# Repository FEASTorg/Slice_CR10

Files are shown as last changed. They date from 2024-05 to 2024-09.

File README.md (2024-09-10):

# 10A Current Reader Slice

10A Current Reader Slice for BREAD.

## Introduction

[Short introduction on the project.]

## Usage

[Explain how to use the project. Include examples and screenshots if applicable.]

## Documentation

Please refer to the [docs](/docs) for more info.

---

<div align="center">
  <p>
    
    
  </p>
</div>

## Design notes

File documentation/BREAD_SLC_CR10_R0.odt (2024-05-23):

# Broadly Reconfigurable and Expandable Automation Device (BREAD) – Slice Datasheet: 10A Current Sensor Slice (SLC-CR10)

By: Nicholas Whisman (ngwhisma@mtu.edu) – Revision 0, on 17. May 2021

## Short Device Description

This slice acts as a current sensor, and is rated for up to ±10 Amps. The sensor outputs a voltage signal linearly related to the current flowing through the chip, at an approximate resolution of 200 mV / Amp.

## Quick Information

Device at a Glance

Short title | 10A Current Detector
Part # | SLC-CR10
Repository Link | Link to OSF or other repository
Academic Paper DOI | DOI link to published paper
Device Cost | Monetary cost of the device
Assembly Difficulty | Medium. Millable.
Application Area | Power Analysis, Controls

Device Connections

Current Input Screw Terminals

Pin # | Description | Rating
J2 | Screw terminal connection points for desired current to measure. Positive lead connects to right side of terminal. | 10A
J3 | Screw terminal connection points for desired current to measure. Positive lead connects to right side of terminal. | 10A
J4 | Screw terminal connection points for desired current to measure. Positive lead connects to right side of terminal. | 10A
J5 | Screw terminal connection points for desired current to measure. Positive lead connects to right side of terminal. | 10A

## Commands

Setup (no significant returns)
Byte: Address | Bit: 1 | Float: Target Temp | Float: Ramp Rate (d/m)
Read Current (returns the current through the selected channel)
Byte: Address | Bit: 0 | Float: 0 | Float: 0

## Schematic

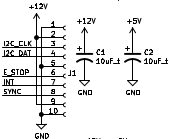
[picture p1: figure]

Figure 1: BREAD Connection Pins + Power Capacitors

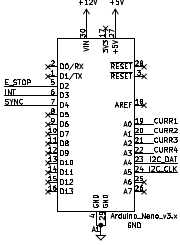
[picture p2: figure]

Figure 2: Arduino Nano

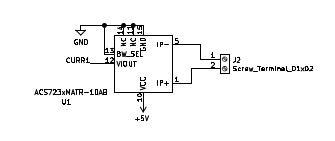
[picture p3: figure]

Figure 3: One of four identical current sensing channels

## Bill of Materials

Designator | Description | Quantity | Cost / part | URL
U1-4 | 10A Current Sensor Chip | 4 | 5.68 | https://www.digikey.com/en/products/detail/allegro-microsystems/ACS723KMATR-10AB-T/5225374
J2-J5 | 1/10” Pitch 01x02 Screw Terminals | 4 | 1.27 | https://www.digikey.com/en/products/detail/te-connectivity-amp-connectors/282834-2/1150135
C1-2 | 1206 Packaging 10 µF Capacitor | 2 | 0.64 | https://www.digikey.com/short/qfrbqfhd
A1 | Arduino Nano | 1 | 22.00 | https://www.digikey.com/en/products/detail/arduino/A000005/2638989
J1 | 01x10 Female Header Pins | 1 | 0.79 | https://www.digikey.com/short/23bfwwjh

## Construction & Fabrication

List any tools that are required and short guide on the order which parts should be soldered / assembled. Be sure to note any specialized methods and point out components that may easily be soldered in the incorrect orientation. Additionally include at least one picture of the assembled board (include both sides if there are components on both sides).

[Image of the assembled Circuit Board]

Fig #. Subtitle should go here.

## Configuration & Calibration

Include a list of default jumper and potentiometer positions:

Hardware Positions

- Turn P1 to be roughly 50%
- Turn P2 to be completely closed (turn clockwise until potentiometer clicks)
- Place a jumper to short out J3. Etc…

Detail any key parameters the end-user may want to adjust in the firmware, and if there are any special instructions before programming the Slice.

Tools Required For Calibration

- An oscilloscope with at least 15Mhz sampling
- A multimeter. Etc…

List all of the tools / instruments required for calibration. Provide a detailed & step by step guide on how to calibrate (or validate) each unique type of channel on the card. Include what variables in the firmware may need to be adjusted (and when). Attach a wiring diagram for each relevant calibration circuit.

[Image of the calibration circuit]

Fig #. Subtitle should go here.

## Usage & Constraints

List the relevant constraints for each type of channel on the card. These parameters may be quantities like max current, max voltage, frequency, sampling frequency, etc.

List an example wiring diagram of the slice in use, as well as some suggested applications

[Image of the example usage wiring diagram]

Fig #. Subtitle should go here.

## General Comments on Slice

This section is intended as a catch-all for any topics that are relevant to the Slice that don’t fit in any other category.

## Revision Notes

- Rev 0 – Initial document release (DATE HERE)

SLC-CR10 Datasheet – Revision 0

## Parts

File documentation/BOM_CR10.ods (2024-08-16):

Id | Designator | Package | Quantity | Designation | Supplier and ref
1 | U4,U3,U2,U1 | SOIC-16W_7.5x10.3mm_P1.27mm | 4 | ACS723KMATR-10AB-T | https://www.mouser.ca/ProductDetail/Allegro-MicroSystems/ACS723KMATR-10AB-T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
2 | J5,J4,J3,J2 | Fixed Terminal Blocks TDPT 4/ 2-SP-6,35-ZB | 4 | Screw_Terminal_01x02 | https://www.mouser.ca/ProductDetail/Phoenix-Contact/1017521?qs=F5EMLAvA7IBBb3TEAcTBBg%3D%3D
3 | C1,C2 | C_2312 | 2 | 10uF_t | https://www.mouser.ca/ProductDetail/Kyocera-AVX/TAJC106K016PNJ?qs=ZjRtS80k2UMUMDO3iOPrkg%3D%3D
4 | A1 | Arduino_Nano | 1 | Arduino_Nano_v3.x | https://www.digikey.ca/en/products/detail/arduino/A000005/2638989
5 | J1 | PinSocket_1x10_P2.54mm_Horizontal | 1 | Conn_01x10_Female | https://www.digikey.ca/en/products/detail/sullins-connector-solutions/PPPC101LGBN-RC/775943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

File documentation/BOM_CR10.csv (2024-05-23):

Id | Designator | Package | Quantity | Designation | Supplier and ref
1 | U4,U3,U2,U1 | SOIC-16W_7.5x10.3mm_P1.27mm | 4 | ACS723xMATR-10AB
2 | J5,J4,J3,J2 | TerminalBlock_TE_282834-2_1x02_P2.54mm_Horizontal | 4 | Screw_Terminal_01x02
3 | Logo1 | OSHW-Symbol_6.7x6mm_SilkScreen | 1 | Logo_Open_Hardware_Small
4 | H4,H3,H2,H1 | MountingHole_3.2mm_M3_DIN965_Pad | 4 | MountingHole
5 | C1,C2 | C_2312 | 2 | 10uF_t
6 | A1 | Arduino_Nano | 1 | Arduino_Nano_v3.x
7 | J1 | PinSocket_1x10_P2.54mm_Horizontal | 1 | Conn_01x10_Female

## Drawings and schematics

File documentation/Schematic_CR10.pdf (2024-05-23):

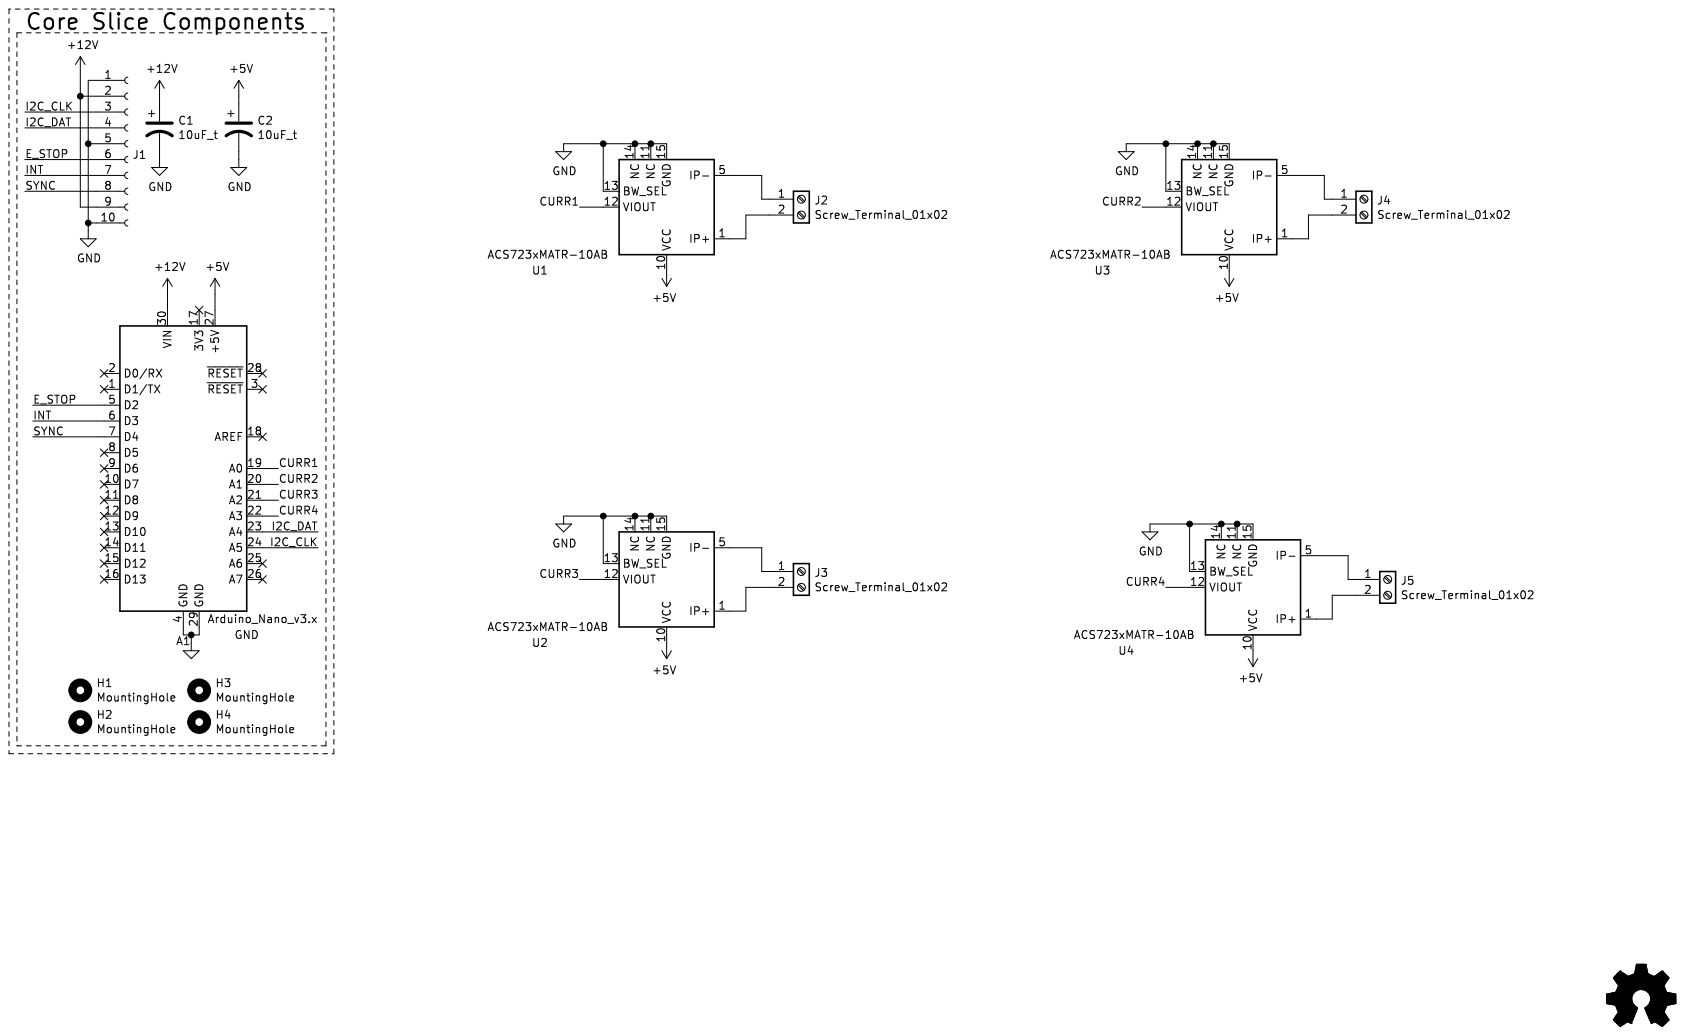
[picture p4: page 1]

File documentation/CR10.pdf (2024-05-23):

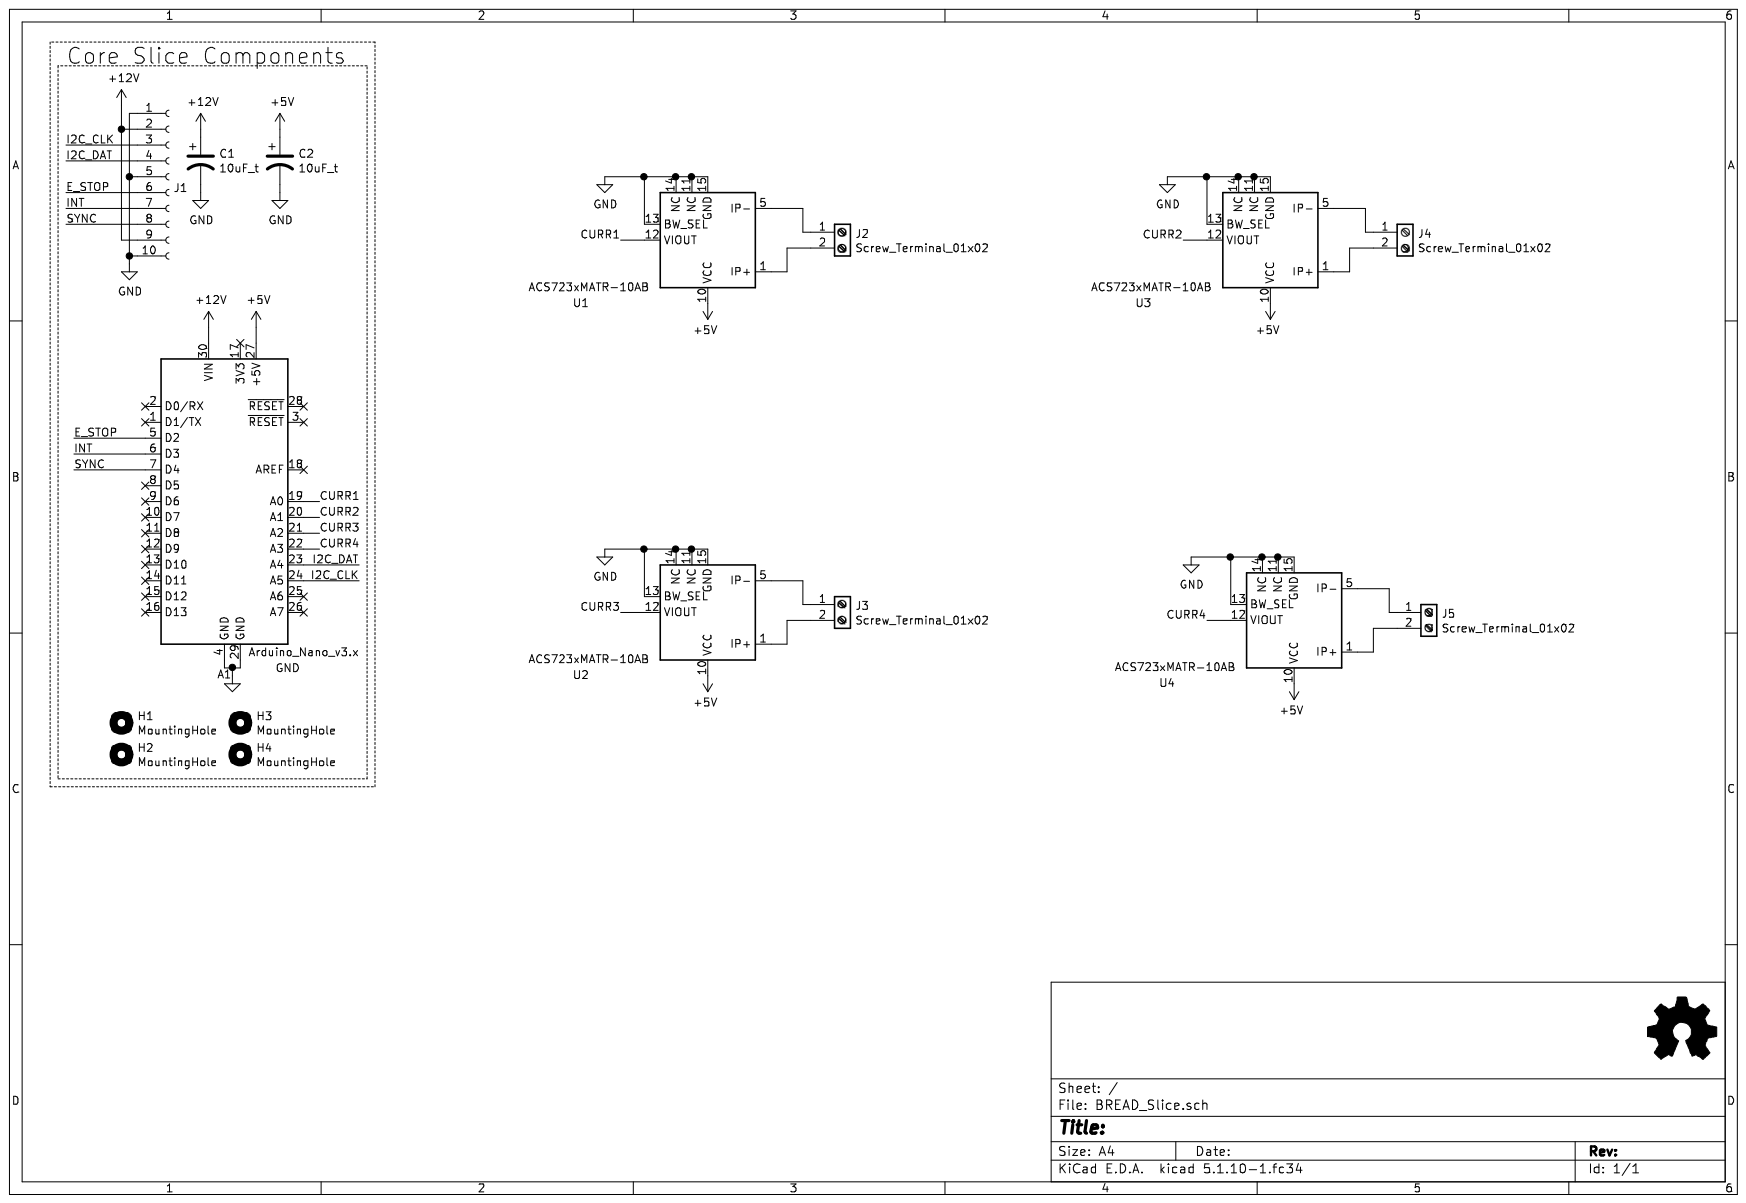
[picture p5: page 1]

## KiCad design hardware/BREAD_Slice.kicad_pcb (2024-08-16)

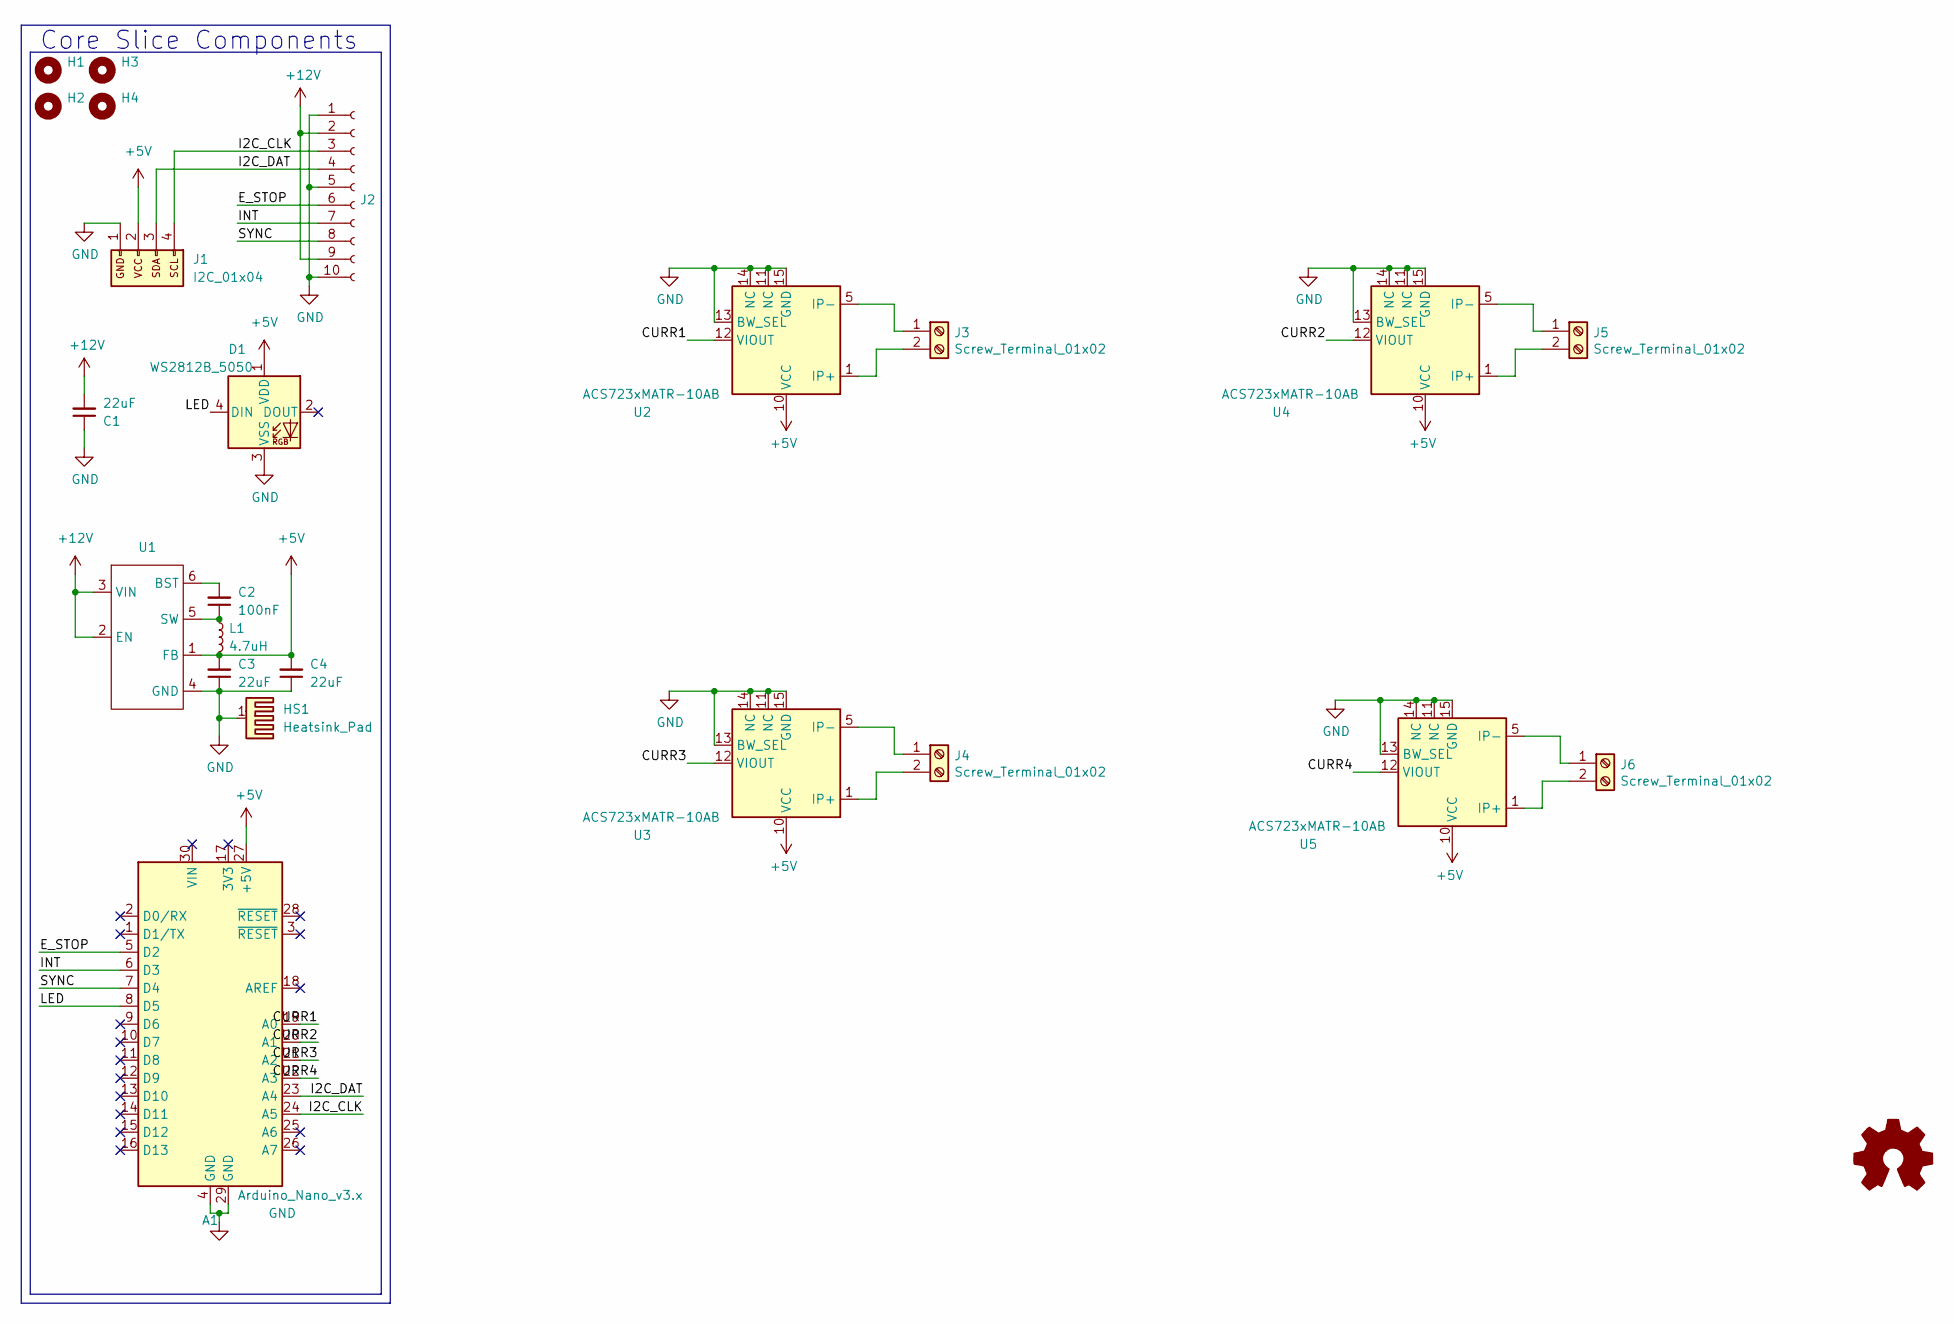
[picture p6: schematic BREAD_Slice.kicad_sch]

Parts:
A1: Arduino_Nano_v3.x; Arduino_Nano
C1, C3, C4: 22uF; C_1206_3216Metric
C2: 100nF; C_1206_3216Metric
D1: WS2812B_5050; WS2812-5050-4PIN
H1, H2, H3, H4: MountingHole; MountingHole_5mm
HS1: Heatsink_Pad; Thermal Pad
J1: I2C_01x04; JST_SH_SM04B-SRSS-TB_1x04-1MP_P1.00mm_Horizontal
J2: Conn_01x10_Female; PinSocket_1x10_P2.54mm_Horizontal
J3, J4, J5, J6: Screw_Terminal_01x02; Pheonix Conn Term TDPT 4 2-SP-6,35-ZB
L1: 4.7uH; L_1210_3225Metric
U1: TSOT-23-6
U2, U3, U4, U5: ACS723xMATR-10AB; SOIC-16W_7.5x10.3mm_P1.27mm

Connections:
+5V: A1.27 (+5V), C3.2, C4.2, D1.1 (VDD), J1.2, L1.2, U1.1 (FB), U2.10 (VCC), U3.10 (VCC), U4.10 (VCC), U5.10 (VCC)
+12V: C1.2, J2.2, J2.9, U1.2 (EN), U1.3 (VIN)
/CURR1: A1.19 (A0), U2.12 (VIOUT)
/CURR2: A1.20 (A1), U4.12 (VIOUT)
/CURR3: A1.21 (A2), U3.12 (VIOUT)
/CURR4: A1.22 (A3), U5.12 (VIOUT)
/E_STOP: A1.5 (D2), J2.6
/I2C_CLK: A1.24 (A5), J1.4, J2.3
/I2C_DAT: A1.23 (A4), J1.3, J2.4
/INT: A1.6 (D3), J2.7
/LED: A1.8 (D5), D1.4 (DIN)
/SYNC: A1.7 (D4), J2.8
GND: A1.4 (GND), A1.29 (GND), C1.1, C3.1, C4.1, D1.3 (VSS), HS1.1, J1.1, J2.1, J2.5, J2.10, U1.4 (GND), U2.11 (NC), U2.13 (BW_SEL), U2.14 (NC), U2.15 (GND), U3.11 (NC), U3.13 (BW_SEL), U3.14 (NC), U3.15 (GND), U4.11 (NC), U4.13 (BW_SEL), U4.14 (NC), U4.15 (GND), U5.11 (NC), U5.13 (BW_SEL), U5.14 (NC), U5.15 (GND)
unnamed: J3.1, U2.5 (IP-), U2.6 (IP-), U2.7 (IP-), U2.8 (IP-)
unnamed: J3.2, U2.1 (IP+), U2.2 (IP+), U2.3 (IP+), U2.4 (IP+)
unnamed: J4.1, U3.5 (IP-), U3.6 (IP-), U3.7 (IP-), U3.8 (IP-)
unnamed: J4.2, U3.1 (IP+), U3.2 (IP+), U3.3 (IP+), U3.4 (IP+)
unnamed: J5.1, U4.5 (IP-), U4.6 (IP-), U4.7 (IP-), U4.8 (IP-)
unnamed: J5.2, U4.1 (IP+), U4.2 (IP+), U4.3 (IP+), U4.4 (IP+)
unnamed: J6.1, U5.5 (IP-), U5.6 (IP-), U5.7 (IP-), U5.8 (IP-)
unnamed: J6.2, U5.1 (IP+), U5.2 (IP+), U5.3 (IP+), U5.4 (IP+)
unnamed: C2.2, U1.6 (BST)
unnamed: C2.1, L1.1, U1.5 (SW)

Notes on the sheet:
Core Slice Components

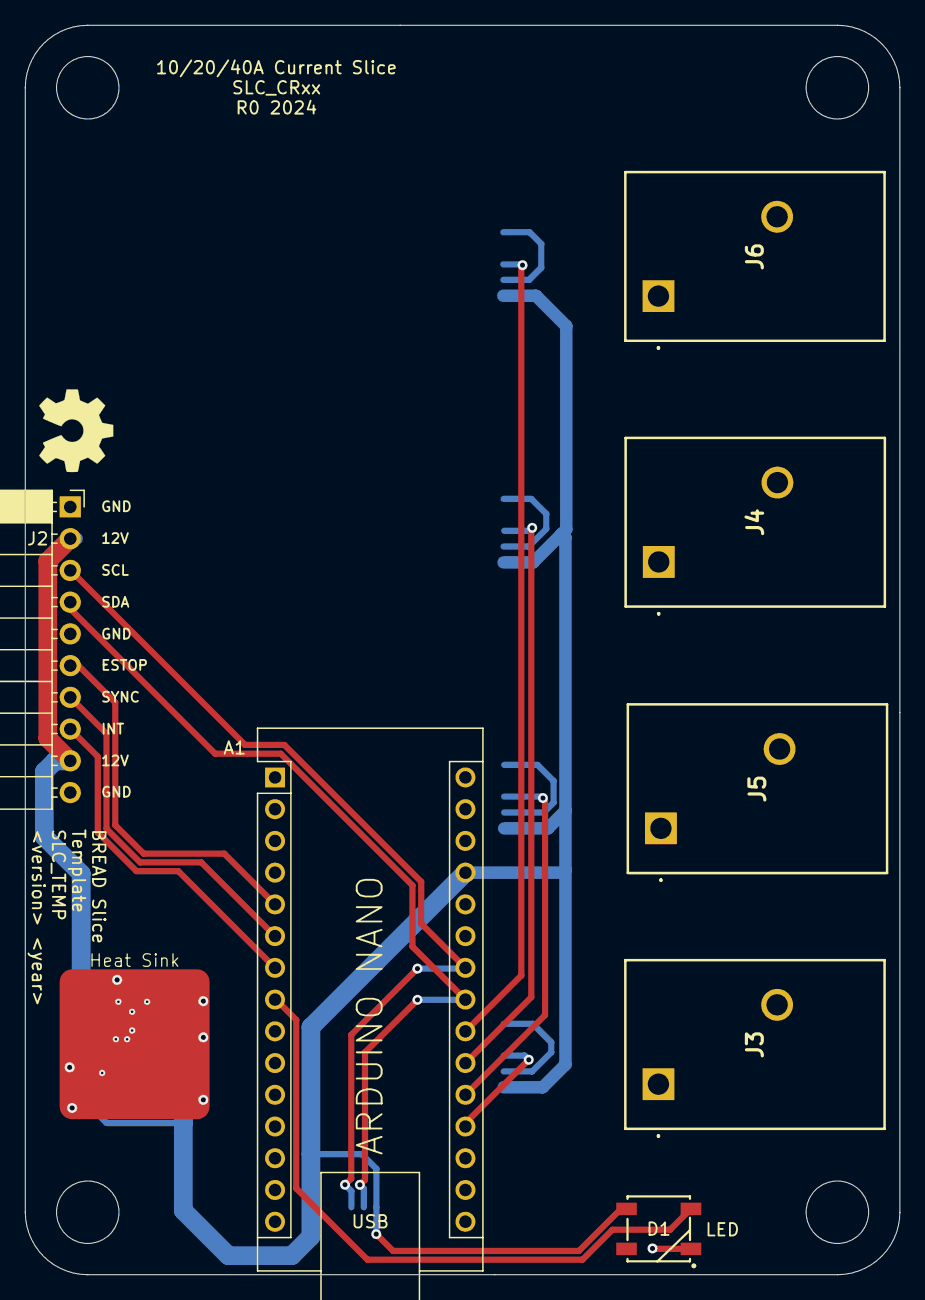
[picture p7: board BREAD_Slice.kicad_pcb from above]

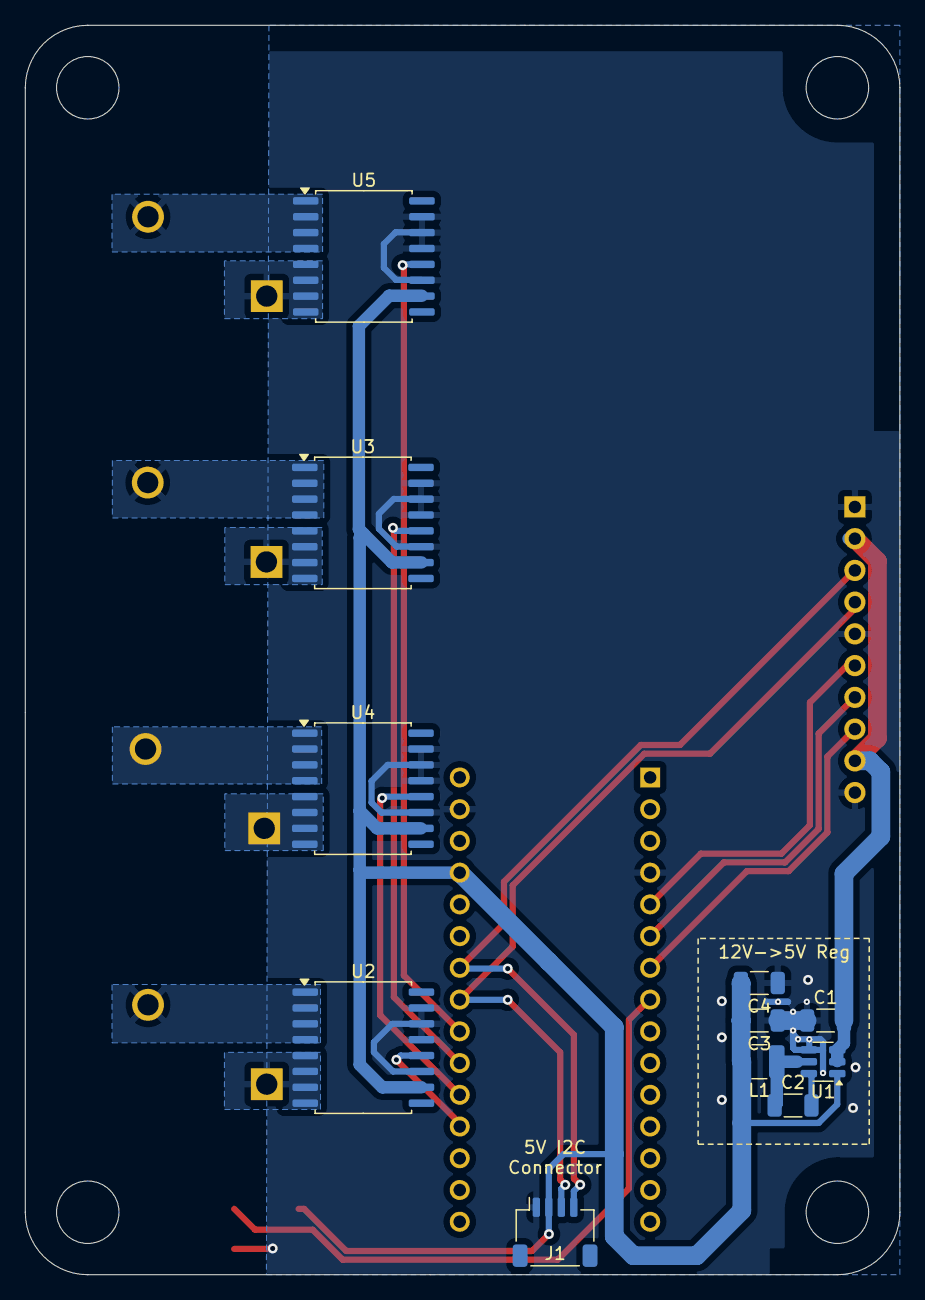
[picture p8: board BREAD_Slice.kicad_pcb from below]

Board: 2 copper layers, 70.0 x 100.0 mm, 24 parts (11 on the bottom side), 23 nets.

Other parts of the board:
Logo1: Logo_Open_Hardware_Small; OSHW-Symbol_6.7x6mm_SilkScreen

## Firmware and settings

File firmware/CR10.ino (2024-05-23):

#include <Wire.h>
#include <SPI.h>

#define I2C_ADR 18 //Set this however you want

typedef union //Define a float that can be broken up and sent via I2C
{
 float number;
 uint8_t bytes[4];
} FLOATUNION_t;

FLOATUNION_t RX_P1;
FLOATUNION_t RX_P2;
FLOATUNION_t RX_P3;
FLOATUNION_t RX_P4;


#define CURR1 A0
#define CURR2 A1
#define CURR3 A2
#define CURR4 A3

double CH1, CH2, CH3, CH4;

//Default all channels enabled
int CH1_T = 1;
int CH2_T = 1;
int CH3_T = 1;
int CH4_T = 1;

String inputString = "";         // a String to hold incoming data
boolean stringComplete = false;  // whether the string is complete

void setup() {
  // put your setup code here, to run once:
  Wire.begin(I2C_ADR);                // join i2c bus with address #8
  //Wire.onReceive(receiveEvent); // register event
  Wire.onRequest(requestEvent); // register event

  inputString.reserve(50);

  Serial.begin(115200);

  while (!Serial) delay(1); // wait for Serial on Leonardo/Zero, etc
  delay(500);

}

void loop() {

  //Add some way to read and save 'Zero' current for each channel?
  
  int filterStrength = 50;
  //Read in all current values, low-pass 'em
  for(int i=0; i<filterStrength; i++){
    CH1 += analogRead(CURR1);
    CH2 += analogRead(CURR2);
    CH3 += analogRead(CURR3);
    CH4 += analogRead(CURR4);
  }

  CH1 = ((CH1/filterStrength)*0.0244379275)-12.4;
  CH2 = ((CH2/filterStrength)*0.0244379275)-12.4;
  CH3 = ((CH3/filterStrength)*0.0244379275)-12.4;
  CH4 = ((CH4/filterStrength)*0.0244379275)-12.4;

  //Print em
  Serial.print(CH1); 
  Serial.print(", ");
  Serial.print(CH2); 
  Serial.print(", ");
  Serial.print(CH3);
  Serial.print(", ");
  Serial.println(CH4);

  //test
  //Serial.print(CH1_T); 
  //Serial.print(", ");
  //Serial.print(CH2_T); 
  //Serial.print(", ");
  //Serial.print(CH3_T);
  //Serial.print(", ");
  //Serial.println(CH4_T);



  if (stringComplete) {
    // clear the string:
    inputString = "";
    stringComplete = false;
  }

  //delay(1000);
}

void receiveEvent(int howMany) {
  RX_P1.number = 0; RX_P2.number = 0; RX_P3.number = 0; RX_P4.number = 0;
  int ByteCount = 0;
  while (1 <= Wire.available()) { // loop through all but the last
    if (ByteCount == 0)
    {
      RX_P1.bytes[0] = Wire.read(); // receive a byte as character
    }
    else if (ByteCount == 1)
    {
      RX_P2.bytes[0] = Wire.read(); // receive a byte as character
    }
    else if (ByteCount == 2)
    {
      RX_P3.bytes[0] = Wire.read(); // receive a byte as character
    }
    else if (ByteCount == 3)
    {
      RX_P4.bytes[ByteCount] = Wire.read(); // receive a byte as character
    }
    ByteCount++;
  }
  stringComplete = true;
  CH1_T = RX_P1.number;
  CH2_T = RX_P2.number;
  CH3_T = RX_P3.number;
  CH4_T = RX_P4.number;

}

void requestEvent() {
  //needs changing
  
  RX_P1.number = CH1;
  RX_P2.number = CH2;
  RX_P3.number = CH3;
  RX_P4.number = CH4;
  
  //Send parameters if set to be requested
  if(CH1_T){
    for (int i = 0; i <=3; i++)
    {
      Wire.write(RX_P1.bytes[i]);
    }
  }

  if(CH2_T){
    for (int i = 0; i <=3; i++)
    {
      Wire.write(RX_P2.bytes[i]);
    }
  }

  if(CH3_T){
    for (int i = 0; i <=3; i++)
    {
      Wire.write(RX_P3.bytes[i]);
    }
  }

  if(CH4_T){
    for (int i = 0; i <=3; i++)
    {
      Wire.write(RX_P4.bytes[i]);
    }
  }
}


// This needs to be changed to I2C stuff?
void serialEvent() {
  while (Serial.available()) {
    // get the new byte:
    char inChar = (char)Serial.read();
    // add it to the inputString:
    inputString += inChar;
    // if the incoming character is a newline, set a flag so the main loop can
    // do something about it:
    if (inChar == '\n') {
      stringComplete = true;

      CH1_T = inputString.substring(0).toInt();
      Serial.println("Got it!");
      CH2_T = inputString.substring(2).toInt();
      Serial.println("Got it!");
      CH3_T = inputString.substring(4).toInt();
      Serial.println("Got it!");
      CH4_T = inputString.substring(6).toInt();
      Serial.println("Got it!");
      
    }
  }
}

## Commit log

2024-08-16 updated to new BREAD format
    [BREAD_Slice-B_Cu.gbr, BREAD_Slice-B_Mask.gbr, BREAD_Slice-B_Silkscreen.gbr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]
2024-08-16 removed legacy hardware
    [BREAD_Slice-B_Cu.gbr, BREAD_Slice-B_Mask.gbr, BREAD_Slice-B_Silkscreen.gbr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]
2024-08-16 updated for CRxx forking
    [BOM_CR10.ods, BREAD_Slice.kicad_pcb, BREAD_Slice.kicad_sch]
